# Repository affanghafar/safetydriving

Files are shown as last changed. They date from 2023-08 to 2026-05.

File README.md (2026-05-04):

# Driver Drowsiness Detection System using Heart Rate and Postural Changes

## Overview
This project develops a driver drowsiness detection system using physiological and motion data. The system combines heart rate signals and postural changes to classify driver fatigue levels using a Fuzzy Inference System.

---

## System Overview

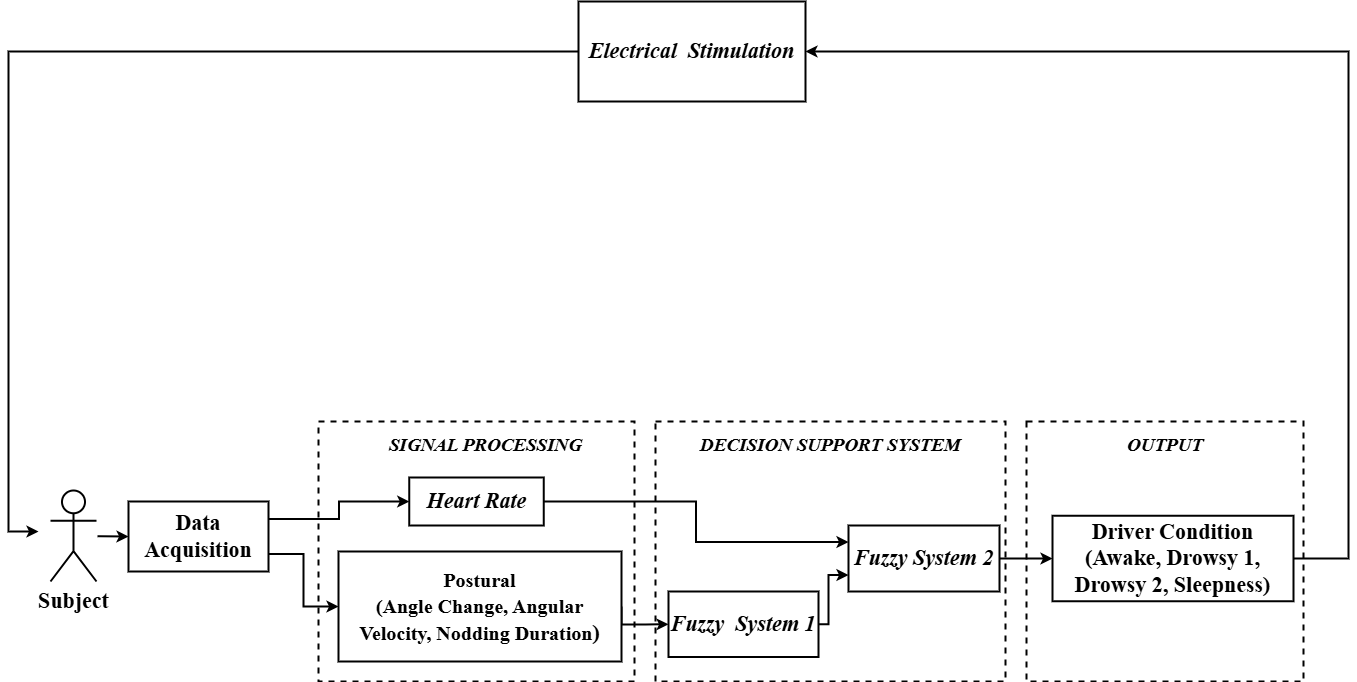
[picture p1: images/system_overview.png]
System Diagram


*Overall functional system diagram for driver drowsiness detection.*

---

## Hardware & Instrumentation

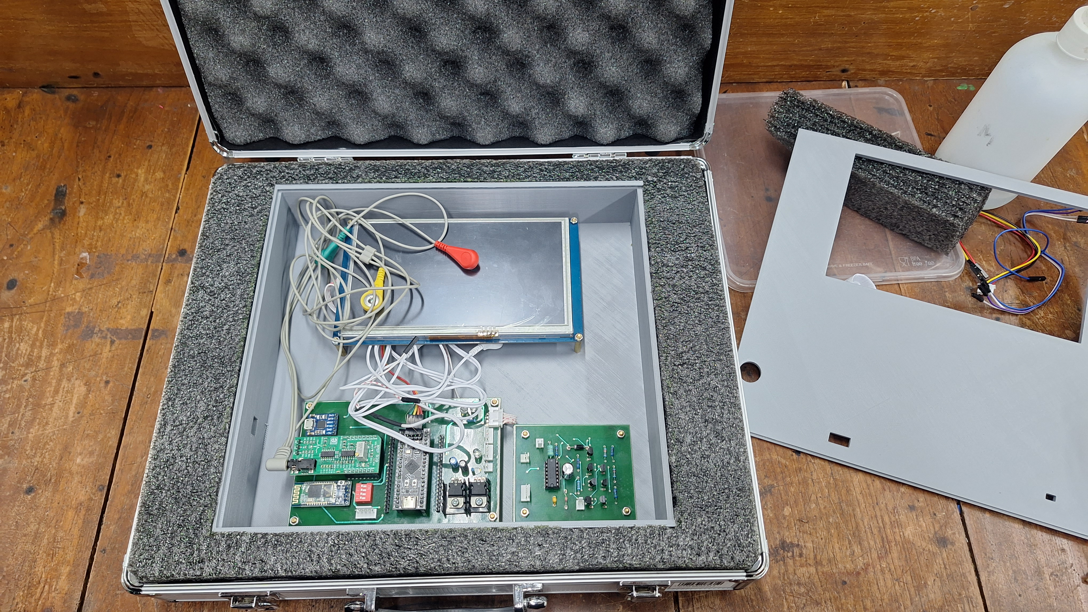
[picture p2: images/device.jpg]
Device


*Prototype device for acquiring ECG and postural data.*

---

## User Interface

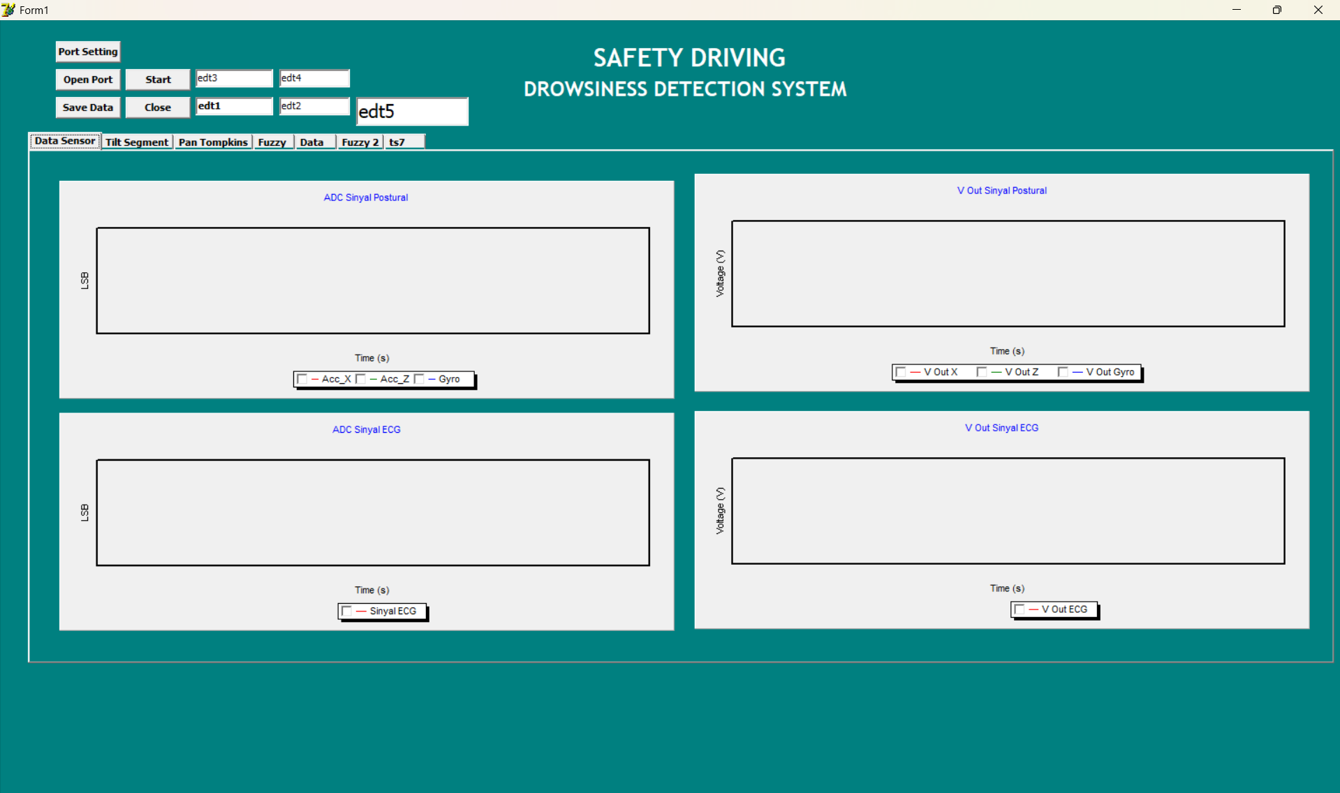
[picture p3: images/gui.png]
GUI


*Graphical user interface for monitoring and visualization.*

---

## Data Acquisition

### ECG Signal Acquisition
ECG Diagram

*Acquisition of heart rate signals using ECG sensor.*

---

### Postural Data Acquisition
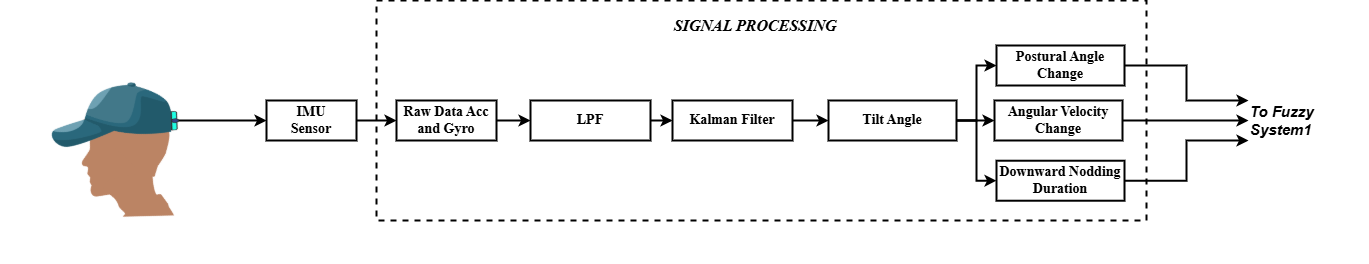
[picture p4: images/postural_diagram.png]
Postural Diagram


*Measurement of head movement and postural changes.*

---

## Hardware Design

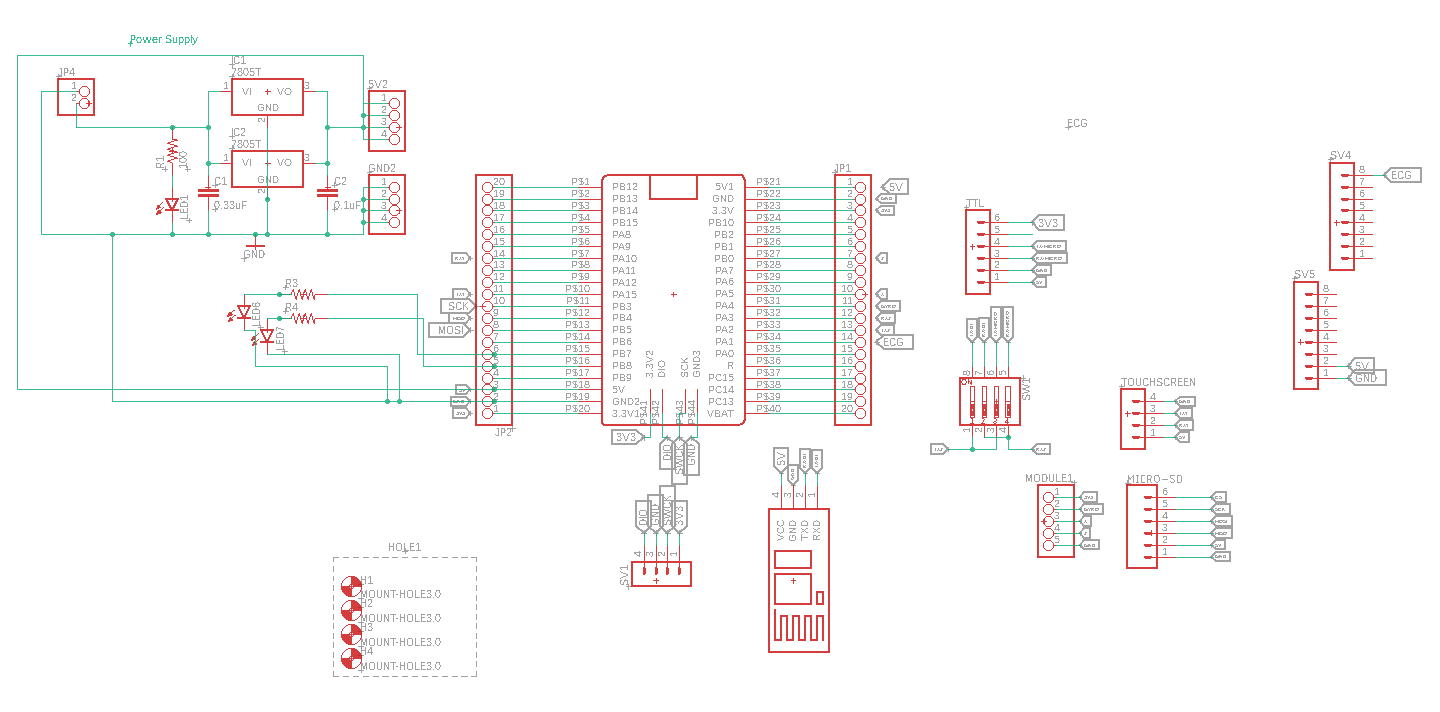
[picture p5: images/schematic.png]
Schematic


*Circuit schematic of the embedded system including ECG sensor and motion sensors.*

## Features

### Physiological Features
- Heart Rate (BPM)

### Postural Features
- Head angle
- Angular velocity
- Nodding duration

---

## Methodology

- Signal acquisition from ECG and motion sensors
- Feature extraction from physiological and postural data
- Classification using **Fuzzy Inference System (FIS)**

---

## Key Findings

- Heart rate tends to decrease during drowsiness
- Postural angle and nodding duration increase
- Angular velocity decreases as fatigue increases

---

## Performance

- Achieved overall accuracy of **87.14%**

---

## Technologies
- Embedded System (STM32)
- Signal Processing
- ECG Sensor
- Accelerometer & Gyroscope
- Fuzzy Logic (FIS)

---

## Project Structure
- `embedded/` – Embedded system code  
- `interface/` – GUI application  
- `hardware/` – PCB and device design  
- `images/` – Diagrams and visualization assets  

---

## Author
Afan Ghafar

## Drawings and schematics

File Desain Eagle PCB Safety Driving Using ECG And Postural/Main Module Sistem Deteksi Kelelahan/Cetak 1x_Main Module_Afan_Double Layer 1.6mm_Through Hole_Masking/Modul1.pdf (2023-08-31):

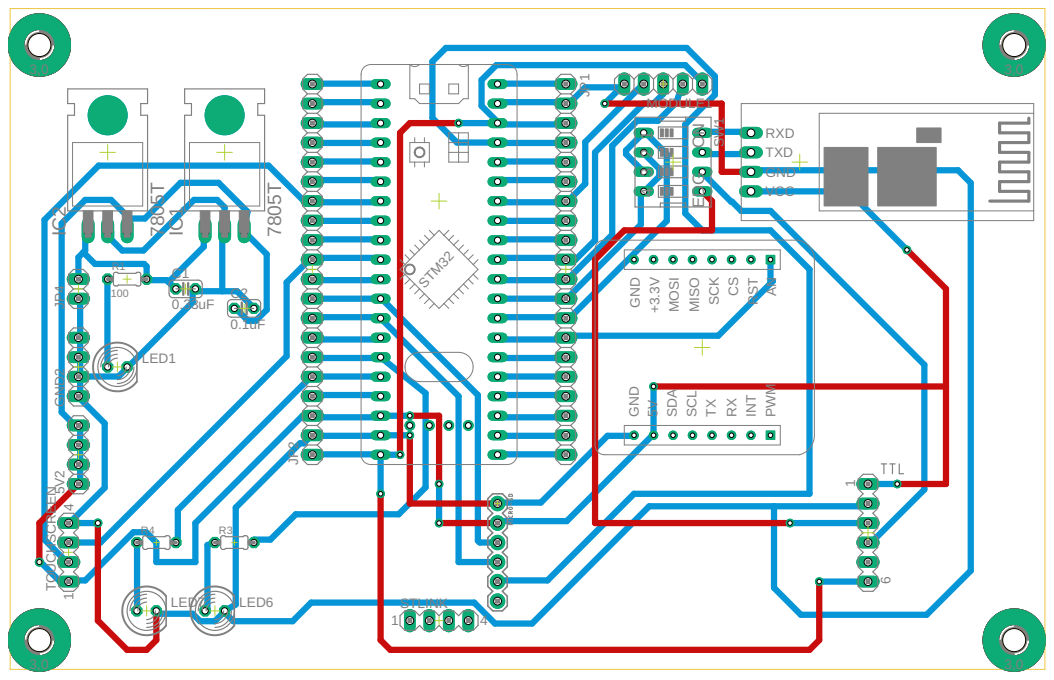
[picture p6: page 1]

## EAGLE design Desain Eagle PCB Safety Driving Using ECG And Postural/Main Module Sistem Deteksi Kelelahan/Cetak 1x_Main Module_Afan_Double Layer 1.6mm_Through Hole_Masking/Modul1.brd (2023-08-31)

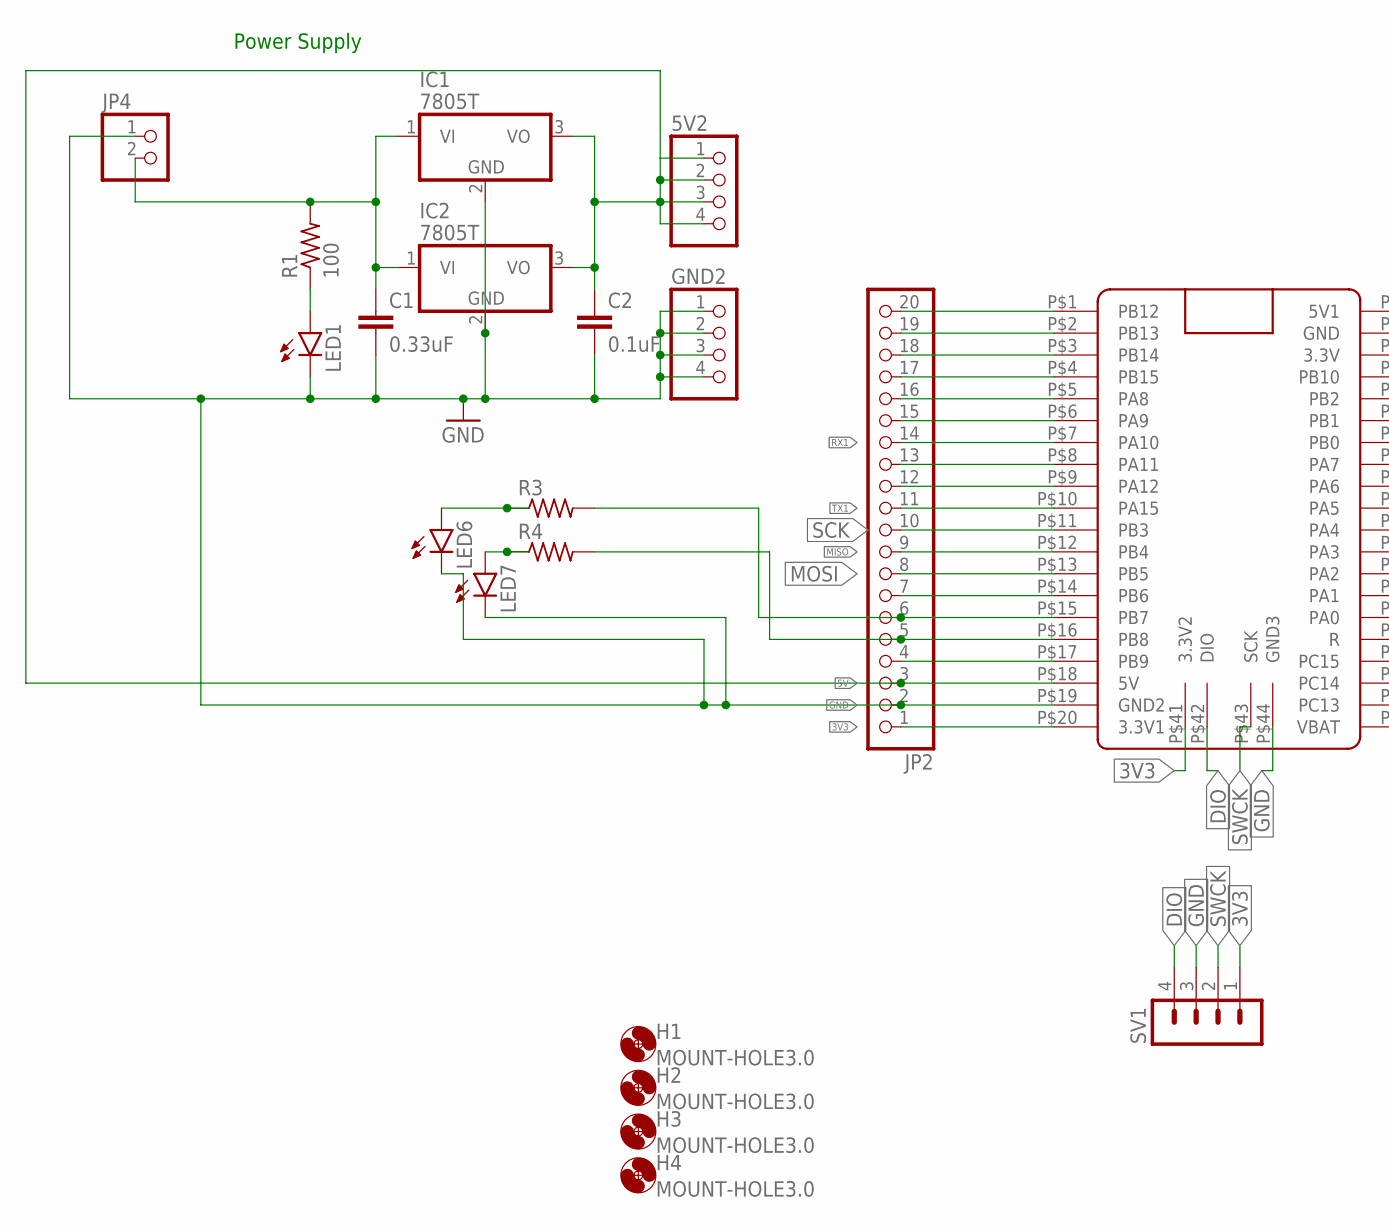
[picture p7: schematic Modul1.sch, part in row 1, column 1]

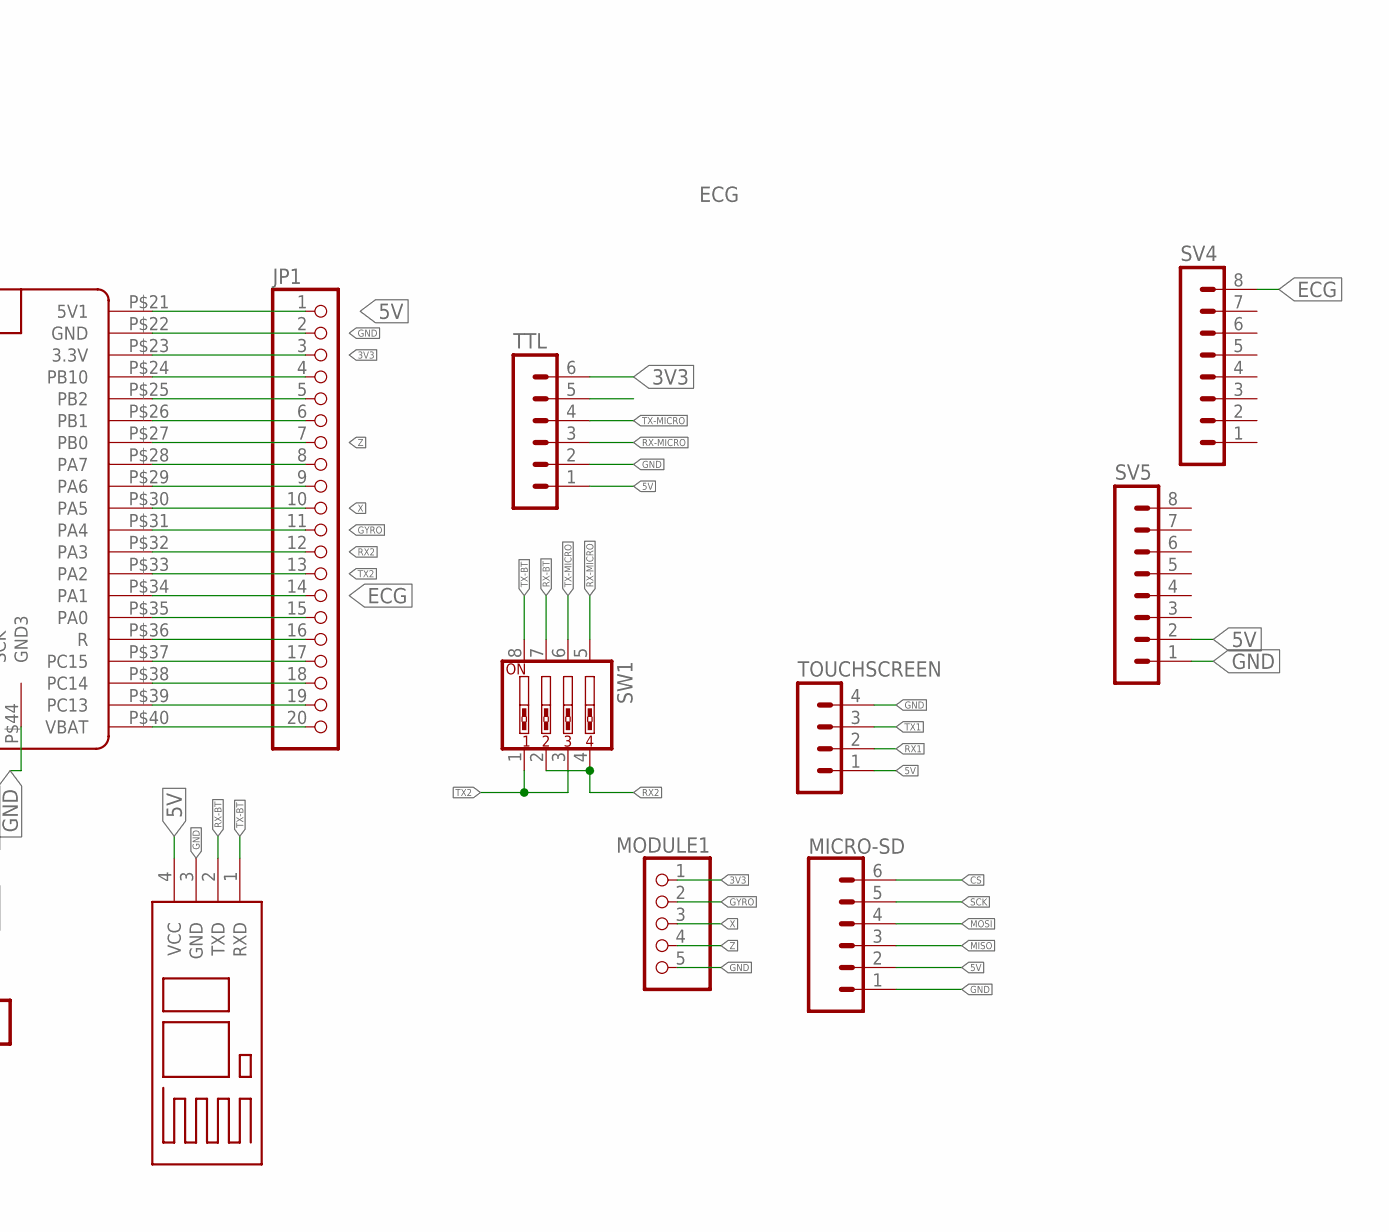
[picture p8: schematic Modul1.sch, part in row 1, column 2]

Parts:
5V2: PINHD-1X4; 1X04
B3: BLUETOOTH
C1: 0.33uF; C025-024X044
C2: 0.1uF; C025-024X044
GND2: PINHD-1X4; 1X04
H1, H2, H3, H4: MOUNT-HOLE3.0; 3,0
IC1, IC2: 7805T; TO220H
JP1, JP2: PINHD-1X20; 1X20
JP4: PINHD-1X2; 1X02
LED1, LED6, LED7: LED5MM
MICRO-SD: CONN_06SILK_FEMALE_PTH; 1X06@1
MODULE1: PINHD-1X5; 1X05
R1: 100; 0204/5
R3, R4: R-US_0204/5; 0204/5
SV1: MA04-1
SV4, SV5: MA08-1
SW1: SW_DIP-4; EDG-04
TOUCHSCREEN: MA04-1
TTL: MA06-1
U$1: BLACKPILL

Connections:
3V3: JP1.3, JP2.1, MODULE1.1, SV1.1, TTL.6, U$1.P$20 (3.3V1), U$1.P$23 (3.3V), U$1.P$41 (3.3V2)
5V: 5V2.1, 5V2.2, 5V2.3, 5V2.4, B3.4 (VCC), C2.1, IC1.3 (VO), IC2.3 (VO), JP1.1, JP2.3, MICRO-SD.2, SV5.2, TOUCHSCREEN.1, TTL.1, U$1.P$18 (5V), U$1.P$21 (5V1)
CS: MICRO-SD.6
DIO: SV1.4, U$1.P$42 (DIO)
ECG: JP1.14, SV4.8, U$1.P$34 (PA1)
GND: B3.3 (GND), C1.2, C2.2, GND2.1, GND2.2, GND2.3, GND2.4, IC1.2 (GND), IC2.2 (GND), JP1.2, JP2.2, JP4.1, LED1.K (C), LED6.K (C), LED7.K (C), MICRO-SD.1, MODULE1.5, SV1.3, SV5.1, TOUCHSCREEN.4, TTL.2, U$1.P$19 (GND2), U$1.P$22 (GND), U$1.P$44 (GND3)
GYRO: JP1.11, MODULE1.2, U$1.P$31 (PA4)
MISO: JP2.9, MICRO-SD.3, U$1.P$12 (PB4)
MOSI: JP2.8, MICRO-SD.4, U$1.P$13 (PB5)
unnamed: JP2.20, U$1.P$1 (PB12)
unnamed: JP2.19, U$1.P$2 (PB13)
unnamed: JP2.18, U$1.P$3 (PB14)
unnamed: C1.1, IC1.1 (VI), IC2.1 (VI), JP4.2, R1.2
unnamed: JP1.8, U$1.P$28 (PA7)
unnamed: JP1.4, U$1.P$24 (PB10)
unnamed: LED1.A, R1.1
unnamed: JP2.12, U$1.P$9 (PA12)
unnamed: JP2.5, R4.2, U$1.P$16 (PB8)
unnamed: LED6.A, R3.1
unnamed: LED7.A, R4.1
unnamed: JP2.7, U$1.P$14 (PB6)
unnamed: JP1.20, U$1.P$40 (VBAT)
unnamed: JP1.19, U$1.P$39 (PC13)
unnamed: JP1.18, U$1.P$38 (PC14)
unnamed: JP1.17, U$1.P$37 (PC15)
unnamed: JP1.16, U$1.P$36 (R)
unnamed: JP1.5, U$1.P$25 (PB2)
unnamed: JP1.6, U$1.P$26 (PB1)
unnamed: JP1.15, U$1.P$35 (PA0)
RX1: JP2.14, TOUCHSCREEN.2, U$1.P$7 (PA10)
RX2: JP1.12, SW1.2, SW1.4, U$1.P$32 (PA3)
RX-BT: B3.2 (TXD), SW1.7
RX-MICRO: SW1.5, TTL.3
SCK: JP2.10, MICRO-SD.5, U$1.P$11 (PB3)
SDA: JP2.4, U$1.P$17 (PB9)
SDIO_CK: JP2.17, U$1.P$4 (PB15)
SDIO_CMD: JP1.9, U$1.P$29 (PA6)
SDIO_D0: JP2.6, R3.2, U$1.P$15 (PB7)
SDIO_D1: JP2.16, U$1.P$5 (PA8)
SDIO_D2: JP2.15, U$1.P$6 (PA9)
SWCK: SV1.2, U$1.P$43 (SCK)
TX1: JP2.11, TOUCHSCREEN.3, U$1.P$10 (PA15)
TX2: JP1.13, SW1.1, SW1.3, U$1.P$33 (PA2)
TX6: JP2.13, U$1.P$8 (PA11)
TX-BT: B3.1 (RXD), SW1.8
TX-MICRO: SW1.6, TTL.4
X: JP1.10, MODULE1.3, U$1.P$30 (PA5)
Z: JP1.7, MODULE1.4, U$1.P$27 (PB0)

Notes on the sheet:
ECG
Power Supply

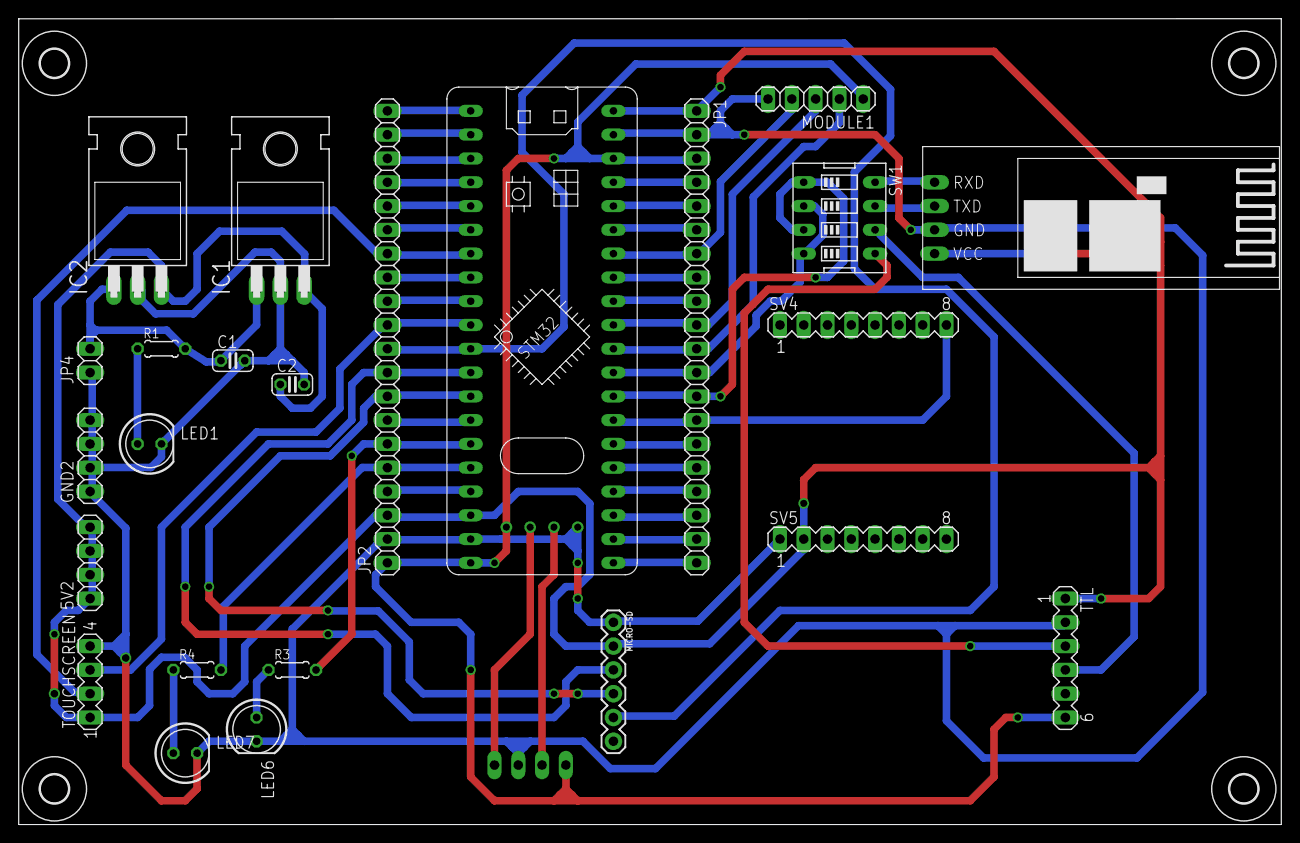
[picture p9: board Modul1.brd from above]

Board: 2 copper layers, 134.8 x 86.0 mm, 29 parts (1 on the bottom side), 47 nets.

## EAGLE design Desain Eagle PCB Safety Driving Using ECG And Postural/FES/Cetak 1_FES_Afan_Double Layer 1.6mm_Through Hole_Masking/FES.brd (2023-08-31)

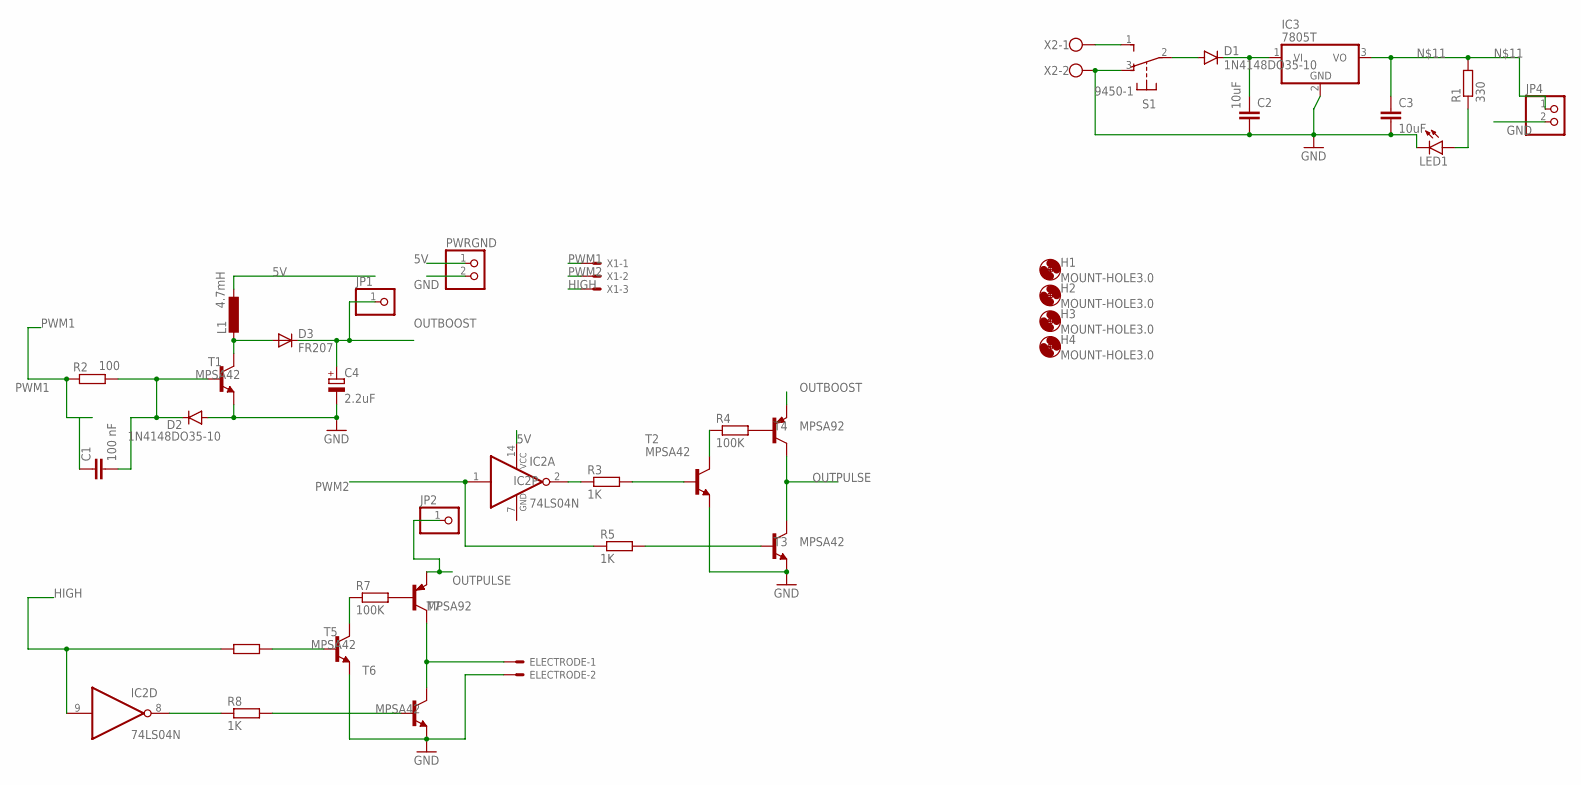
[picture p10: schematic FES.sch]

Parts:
C1: 100 nF; C5B2.5
C2, C3: 10uF; C2.5-2
C4: 2.2uF; E5-10,5
D1, D2: 1N4148DO35-10; DO35-10
D3: FR207; DO15-12
ELECTRODE: 22-23-2021
H1, H2, H3, H4: MOUNT-HOLE3.0; 3,0
IC2: 74LS04N; DIL14
IC3: 7805T; TO220H
JP1, JP2: PINHD-1X1; 1X01
JP4: PINHD-1X2; 1X02
L1: 4.7mH; 0207/12
LED1: LED3MM
PWRGND: PINHD-1X2; 1X02
R1: 330; 0207/10
R2: 100; 0207/10
R3, R5, R6, R8: 1K; 0207/10
R4, R7: 100K; 0207/10
S1: 9450-1
T1, T2, T3, T5, T6: MPSA42; TO92-EBC
T4, T7: MPSA92; TO92-EBC
X1: 22-23-2031
X2: W237-102

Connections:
5V: IC2.14 (VCC), L1.1, PWRGND.1
GND: C2.2, C3.2, C4.-, D2.A, ELECTRODE.2, IC2.7 (GND), IC3.2 (GND), JP4.2, LED1.K (C), PWRGND.2, S1.3 (O), T1.E, T2.E, T3.E, T5.E, T6.E, X2.2
HIGH: IC2.9 (I), R6.1, X1.3
unnamed: C1.2, D2.C, R2.2, T1.B
unnamed: S1.1 (S), X2.1
unnamed: D3.A, L1.2, T1.C
unnamed: C2.1, D1.C, IC3.1 (VI)
unnamed: R4.2, T4.B
unnamed: IC2.2 (O), R3.1
unnamed: R3.2, T2.B
unnamed: R4.1, T2.C
unnamed: R7.2, T7.B
unnamed: C3.1, IC3.3 (VO), JP4.1, R1.2
unnamed: IC2.8 (O), R8.1
unnamed: R5.2, T3.B
unnamed: R6.2, T5.B
unnamed: R7.1, T5.C
unnamed: ELECTRODE.1, T6.C, T7.C
unnamed: R8.2, T6.B
unnamed: LED1.A, R1.1
unnamed: D1.A, S1.2
OUTBOOST: C4.+, D3.C, JP1.1, T4.E
OUTPULSE: JP2.1, T3.C, T4.C, T7.E
PWM1: C1.1, R2.1, X1.1
PWM2: IC2.1 (I), R5.1, X1.2

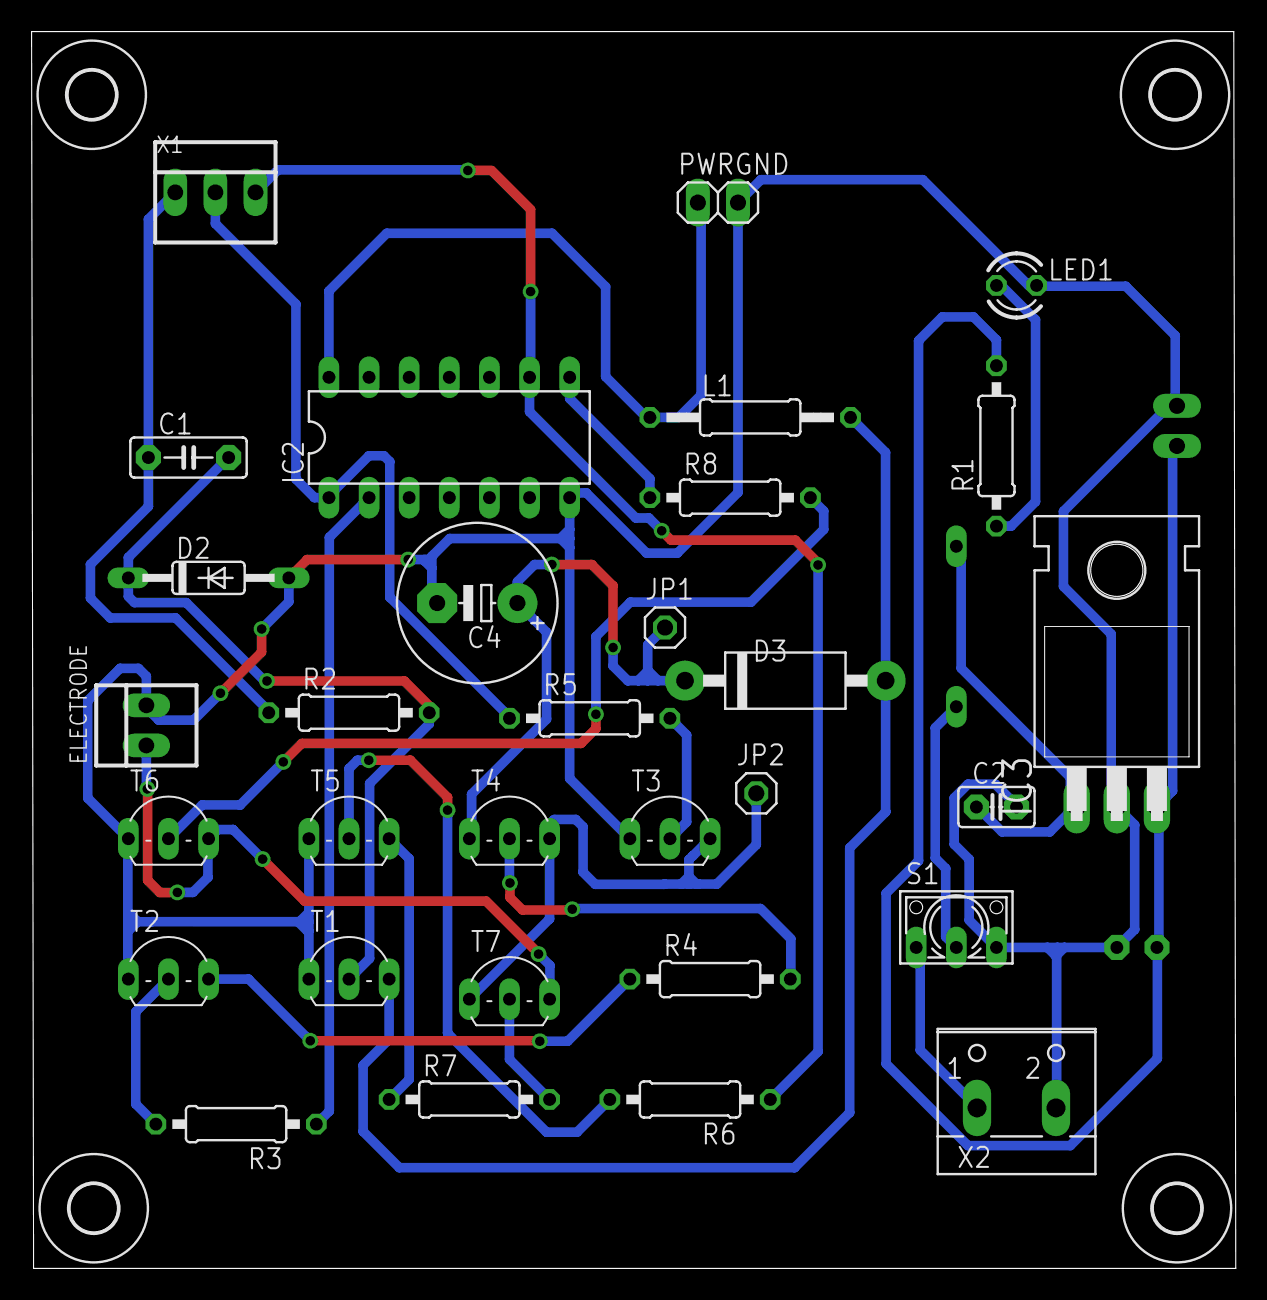
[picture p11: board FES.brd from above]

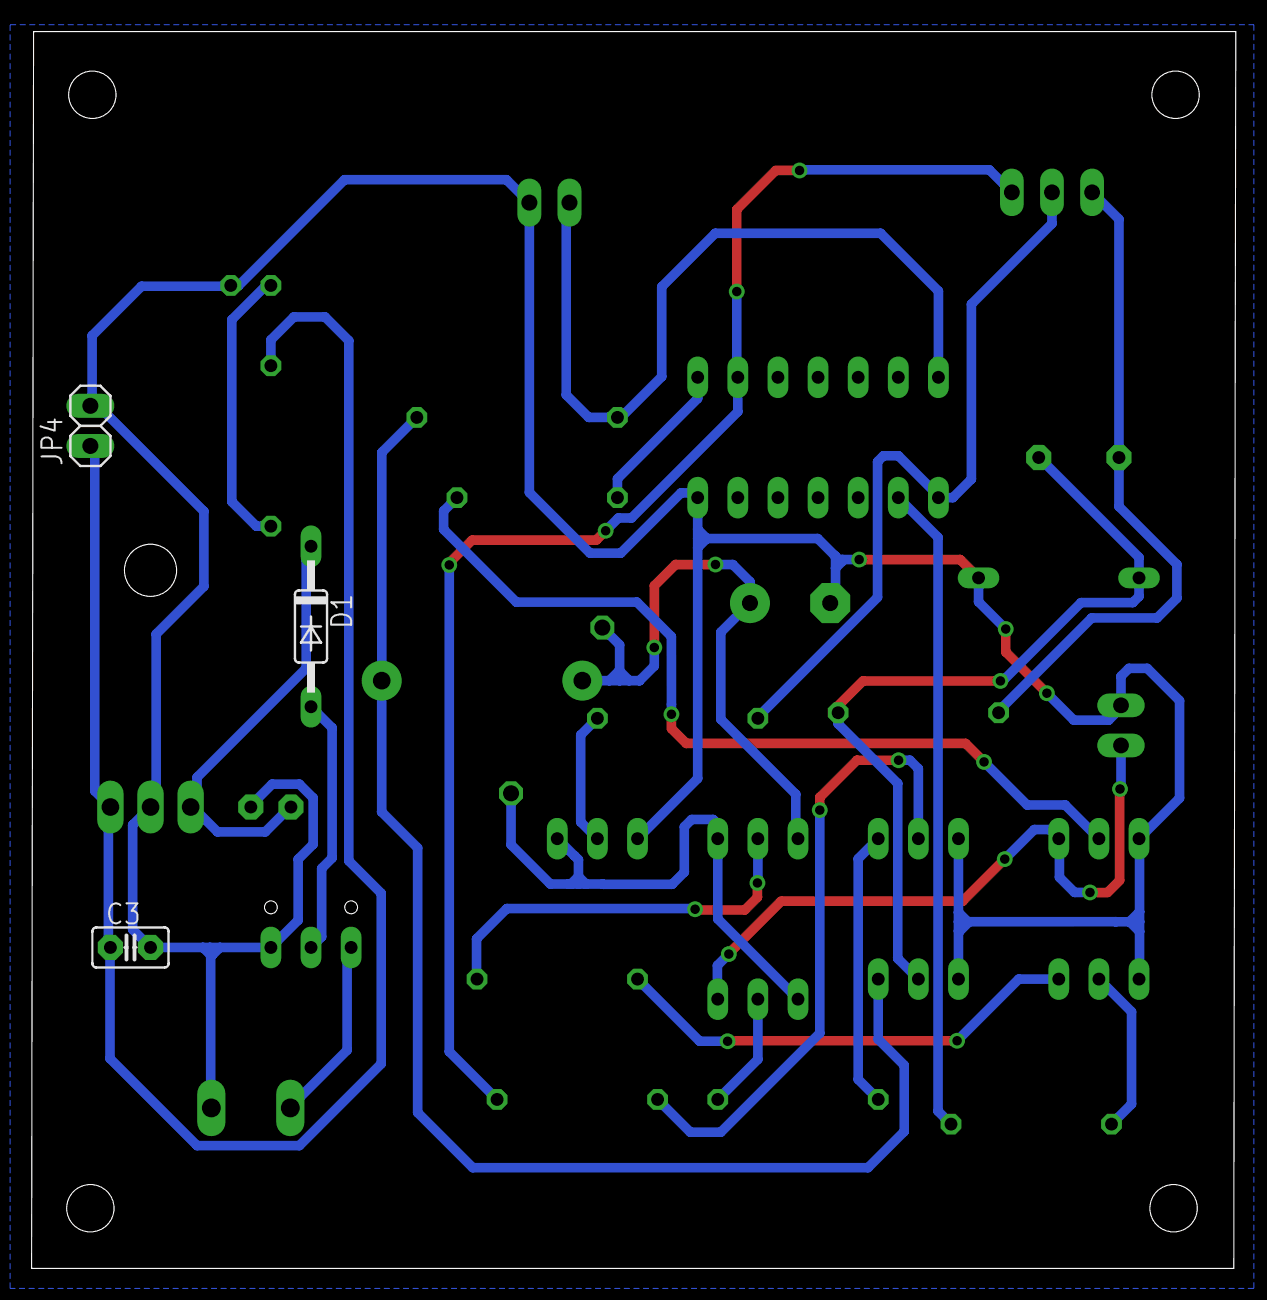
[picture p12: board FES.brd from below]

Board: 2 copper layers, 76.2 x 78.3 mm, 38 parts (3 on the bottom side), 25 nets.

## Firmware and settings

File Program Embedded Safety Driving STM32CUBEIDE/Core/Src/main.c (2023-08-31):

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
/* Includes ------------------------------------------------------------------*/
#include "main.h"
#include "usb_device.h"
#include <math.h>
#include "usbd_cdc_if.h"
#include <malloc.h>
#include "string.h"
#include <stdio.h>
#include <stdlib.h>

ADC_HandleTypeDef hadc1;

SPI_HandleTypeDef hspi1;

TIM_HandleTypeDef htim1;
TIM_HandleTypeDef htim2;
TIM_HandleTypeDef htim4;

UART_HandleTypeDef huart1;
UART_HandleTypeDef huart2;

/* USER CODE BEGIN PV */


uint8_t fsampling=250;
#define filter_length 750 //fs*waktu
#define th 37
int kondisi_sebelum, kondisi_sekarang;
float lpf[filter_length],hpf[filter_length],derivativ[filter_length],squaring[filter_length],moving[filter_length],moving1[filter_length],threshold[filter_length],threshold1[filter_length],threshold2[filter_length],qrs[filter_length],threshold3[filter_length],threshold4[filter_length];
uint16_t Acc1x=0,ecg,gyro1=0, Acc1z=0,Acc1xa,Acc1xb,Acc1za,Acc1zb, gyro1a,gyro1b;
uint8_t rx_data1,rx_data;
uint8_t  myData[24];
uint32_t on=0, off=0, timerCount=0, fes=0, fes2=0, tmr=0;
uint32_t count3=0,count4=0,n=0,count5=0,count2=0,count1=0,windowing=0,p=0,count_rr=0,k=0,z1=0,q1=0,count6=0, count7=0;
uint8_t Cmd_End[3] = {0xFF,0xFF,0xFF};
float d,e,f,g,h,l,hr,ecg_vol[filter_length],durasi,o,t,v;
float a11, b11, c11, d11,e11,f11,g11,h11,l11;
float a22, b22, c22, d22,e22,f22,g22,h22,l22;
int m;
float max_value,ecg_lpf,ecg_hpf,deriv,squar,mav, mav1,thr,bpm1;


//------------------------Const Sinyal ECG----------------------------//


//------------------------Const Untuk Postural----------------------------//
//#define FrekSampling	20			// dalam Hz
//#define dt 				0.05	// dalam detik
#define FrekSampling	250			// dalam Hz
#define dt 				0.004		// dalam detik
#define pi 				3.141593
#define d90 			90
#define Rad2Deg 		57.29578
//0g acc (kalibrasi)
#define UparmAc_X_0g	  (2457+1642)/2//(2537+1393)/2 //(2412+1592)/2//1861.36
#define UparmAc_Z_0g	  (2431+1633)/2//(2472+1345)/2 //(2432+1627)/2
//--------sensitivitas acc (kalibrasi)
#define UparmAc_X_Sens	 (2457-1642)/2//(2537-1393)/2 //(2412-1592)/2
#define UparmAc_Z_Sens	 (2431-1633)/2//(2472-1345)/2 //(2432-1627)/2
//Koefisien Regresi kalibrasi
#define aUparm 	0.9971
#define bUparm 	0.0585
//--------sensitivitas gyro (sesuai data sheet)(4095*0.00067/3.3)
#define GyroSenstvtS 	1.16 //2.7
//--------gyro offset (kalibrasi lsb kondisi diam)
#define Gyro_offset	1671



//ADC_ChannelConfTypeDef sConfig = {0};
/* USER CODE END PV */

void SystemClock_Config(void);
static void MX_GPIO_Init(void);
static void MX_ADC1_Init(void);
static void MX_TIM2_Init(void);
static void MX_USART1_UART_Init(void);
static void MX_USART2_UART_Init(void);
static void MX_SPI1_Init(void);
static void MX_TIM1_Init(void);
static void MX_TIM4_Init(void);

ADC_ChannelConfTypeDef sConfig = {0};
/* USER CODE END PV */
//================== DIGITAL Butterworth LPF ======================//
static const float a1 =  1.6474599811; static const float a2 = 0.7008967812; //4Hz
static const float b0 =  0.0133592000; static const float b1 = 0.0267184001;
static const float b2 =  0.0133592000;
//================== KALMAN FILTER Uparm
static const float QangleS = 0.001;  //tingkat kepercayaan Akselero Uparm
static const float QgyroS  = 0.003;  //tingkat kepercayaan Gyro Uparm
static const float RangleS = 0.04;	 //kemungkinan jiter Akselero Uparm (rad)

float UparmLajuGr, TiltUparmGr, UparmAc_X_Vctr,UparmAc_Z_Vctr,UparmAcclX_LPF, UparmAcclZ_LPF,UparmGyroY_LPF, t=0,miuk ;
float TiltAc=0.0,Tilttemp, TiltKal,GyroUparm, VUparmx,VUparmz,VgyroUparm,sudut[filter_length],velocity[filter_length],signal1[filter_length];
int cntr, Uparmac_a,Uparmac_b,Uparmkal_a,Uparmkal_b,ri;
int gyroUparma,gyroUparmb,gyroUparmc;
int VUparmx_a,VUparmx_b,VUparmz_a,VUparmz_b, VgyroUparm_a,VgyroUparm_b,Vecg_a,Vecg_b;
float ErrEstmt, K0, K1, ErrTilt,error1,tarr,heart_rate;
float Bias_T, P1T, P2T, P3T, P4T,Bias_S, P1S, P2S, P3S, P4S,Bias_F, P1F, P2F, P3F, P4F;
int sinyal[14],sinyal_1[14],sinyal_2[14],Ylpf[14],Ylpf_1[14],Ylpf_2[14];
int sinyal_1_acc1x[14],sinyal_2_acc1x[14],Ylpf_1_acc1x[14],Ylpf_2_acc1x[14];
int sinyal_1_acc1z[14],sinyal_2_acc1z[14],Ylpf_1_acc1z[14],Ylpf_2_acc1z[14];
int sinyal_1_gyro1y[14],sinyal_2_gyro1y[14],Ylpf_1_gyro1y[14],Ylpf_2_gyro1y[14];
int gyroUparma,gyroUparmb,gyroUparmc;

int flag,Program_state, flagkirim, map_ecg,i,Elpf_a,Elpf_b,Ehpf_a,Ehpf_b,panjang_bpm[filter_length];
int deriv_a,deriv_b,squar_a,squar_b, mav_a,mav_b,window,mav_a1,mav_b1,thr_a,thr_b,rr_a,rr_b,rr1_a,rr1_b,bpm_a,bpm_b;
char ecg_kirim[5], ecg_data[20], hasil_data[5],map_hasil;
char Rx_data[1];
float Vecg,Vecg1,count,tho,AN,AP,rr_temp[filter_length],rr1[0][filter_length],nilairr[filter_length];
int count_k[filter_length];
int qrs_hasil;
float ecg_vol1[filter_length], off_ecg_temp,sum,sum_data, kecepatan;
float hasil1[filter_length], hasil2[filter_length], hasil3[filter_length];
float hasil_QRS[filter_length];
float ZrTiltUparmAc, zeroposition;
float signal[filter_length];
float rr_index[filter_length],rr[filter_length],bpm[filter_length];
uint32_t rr_index_length=0,rr_length=0;
//fuzzy
int lop,j,m,q,stmltime,stmltime_1,stmltime2,stmltime_2,stmltime3,stmltime_3,cntrTA;
float a,b,c,jfloat, jfloat1, jfloat2, jfloat3, jfloat4, in1,in2,in3,in4,in5[filter_length],in6[filter_length], in7[filter_length], in8[filter_length], min[24],imfhr[3][3],imfkc[3][3],imfdr[4][4],imfps[3][3],omfstbd[4][4],miu[8],miuerr[8],miudr[8],miumaxstbd[101],maxplantar,maxflexion,maxflexion1;
float maxx,fuzzy_mks[10],ttk[10],num,denum,centroid,AnkKal_Save,AnkKal_Save2,ShoulderKal_Save;
int in1a,in1b,in2a,in2b,in3a,in3b,in4a,in4b,in5a,in5b,centa,centb,centc,centd,cente,centf,gyroShouldera,gyroShoulderb,gyroShoulderc,gyroUparma,gyroUparmb,gyroUparmc,gyroLowarma,gyroLowarmb,gyroLowarmc;
float miu_low[filter_length], miu_vhigh1[filter_length],miu_high[filter_length],miu_low1[filter_length], miu_medium1[filter_length],miu_high1[filter_length],miu_low2[filter_length],miu_high2[filter_length],miu_low3[filter_length],miu_medium3[filter_length],miu_high3[filter_length];
float miuk_low, miuk_medium, miuk_high, miuk_low1, miuk_medium1, miuk_high1,miuk_vhigh1;
float miul_hr, mium_hr, miuh_hr, miul_pos, miuh_pos, miul_kec, miuh_kec,mius_dur,mium_dur,miul_dur,miuvl_dur;
float rule[27], sum_rr = 0.0;
float value_a, value_w1, value_w2, value_w3, outf;
float low_miu, medium_miu, high_miu,max1, max2,max3,max4;
float value_aw, value_dr1, value_dr2,value_sl, value_rmssd;
float miu_low3[filter_length], miu_medium3[filter_length], miu_high3[filter_length],miu_low4[filter_length], miu_medium4[filter_length], miu_high4[filter_length],miu_vhigh4[filter_length];
/* USER CODE BEGIN PFP */



void Kalman(void)
{
	sinyal[1]=Acc1x;
	sinyal[2]=Acc1z;
	sinyal[3]=gyro1;

	//LPF filter
	for (i = 1; i < 4; i++)
	{
		if (i==1){
			Ylpf_2[i] = Ylpf_2_acc1x[i];
			Ylpf_1[i] = Ylpf_1_acc1x[i];
			sinyal_2[i] = sinyal_2_acc1x[i];
			sinyal_1[i] = sinyal_1_acc1x[i];
		}
		else if (i==2){
			Ylpf_2[i] = Ylpf_2_acc1z[i];
			Ylpf_1[i] = Ylpf_1_acc1z[i];
			sinyal_2[i] = sinyal_2_acc1z[i];
			sinyal_1[i] = sinyal_1_acc1z[i];
		}
		else if (i==3){
			Ylpf_2[i] = Ylpf_2_gyro1y[i];
			Ylpf_1[i] = Ylpf_1_gyro1y[i];
			sinyal_2[i] = sinyal_2_gyro1y[i];
			sinyal_1[i] = sinyal_1_gyro1y[i];
		}

		Ylpf[i] = (uint16_t)(a1*((float)Ylpf_1[i])-a2*((float)Ylpf_2[i])+b0*((float)sinyal[i])+b1*((float)sinyal_1[i])+b2*((float)sinyal_2[i]));
		if (Ylpf[i]<0){Ylpf[i]=0;}

		if (i==1){
			Ylpf_2_acc1x[i] = Ylpf_1[i];
			Ylpf_1_acc1x[i] = Ylpf[i];
			sinyal_2_acc1x[i] = sinyal_1[i];
			sinyal_1_acc1x[i] = sinyal[i];
		}
		else if (i==2){
			Ylpf_2_acc1z[i] = Ylpf_1[i];
			Ylpf_1_acc1z[i] = Ylpf[i];
			sinyal_2_acc1z[i] = sinyal_1[i];
			sinyal_1_acc1z[i] = sinyal[i];
		}
		else if (i==3){
			Ylpf_2_gyro1y[i] = Ylpf_1[i];
			Ylpf_1_gyro1y[i] = Ylpf[i];
			sinyal_2_gyro1y[i] = sinyal_1[i];
			sinyal_1_gyro1y[i] = sinyal[i];
		}
	}

	//using lpf
	UparmAcclX_LPF = Ylpf[1];
	UparmAcclZ_LPF = Ylpf[2];
	UparmGyroY_LPF = Ylpf[3];

	UparmAc_X_Vctr = (float)((UparmAcclX_LPF - UparmAc_X_0g)/ UparmAc_X_Sens);
	UparmAc_Z_Vctr = (float)((UparmAcclZ_LPF - UparmAc_Z_0g)/ UparmAc_Z_Sens);


	TiltAc	=  atan2f(UparmAc_Z_Vctr,UparmAc_X_Vctr);


	TiltAc	= TiltAc*Rad2Deg;

//	if (zeroposition==1.0)
//	    	{
//	    		ZrTiltUparmAc	= TiltAc;
////	    		ZeroHip = ZrTiltThighAc - ZrTiltTrunkAc;
//	    		TiltKal = TiltAc;
//	    	}

//---------------------------------KALMAN FILTER------------------------------------//

    //--------------------- Time Update / State Update: ( “Prediksi ? )
    //------ prediksi state
    UparmLajuGr = (float)((UparmGyroY_LPF-Gyro_offset)/GyroSenstvtS);
    TiltKal += (UparmLajuGr - Bias_S)*dt; //TiltUparm = nilai Prediksi

//    GyroUparm += (UparmLajuGr * dt); //TiltShoulder = nilai Prediksi

//    TiltKal = TiltAc - TiltKal;
    // += (UparmLajuGr * dt); //TiltShoulder = nilai Prediksi
    //GyroUparm *= Rad2Deg;

    //------ prediksi matrik Error Covariance
    //??
    P4S += QgyroS * dt;
    P2S -= P4S * dt;
    P3S -= P4S * dt;
    P1S += (QangleS + P4S*dt - P3S - P2S )*dt;

    //--------------------- Measurement Update / Kalman Update (  “Koreksi ? )
    //------ hitung Error Estimate
    //??
    ErrEstmt = P1S + RangleS;

    //------ hitung Kalman filter Gain
    K0 = P1S / ErrEstmt;
    K1 = P3S / ErrEstmt;
    //pembaharuan
    //------ hitung tilt error, selisih nilai measurement - nilai Prediksi state
    ErrTilt  = TiltAc - TiltKal;  //TiltAc = nilai Measurement

    //------ Koreksi nilai estimasi state
    TiltKal += K0 * ErrTilt;  //estimasi sudut tilt Uparm terkoreksi
    Bias_S    += K1 * ErrTilt;  //estimasi bias gyro terkoreksi, perb output dan real

    //------ Koreksi matrik Error Covariance ->utk iterasi berikutnya
    P1S -= K0 * P1S;
    P2S -= K0 * P2S;
    P3S -= K1 * P1S;
    P4S -= K1 * P2S;

//    TiltKal = TiltAc - TiltKal;
}

void vel(void){



 if(count3==0){
	 sudut[count2]=TiltKal;

	 if(count2==0) velocity[count2]=0.0;
	 else velocity[count2]=(sudut[count2]-sudut[count2-1])/dt;
 }
 else{
	 sudut[count2]=TiltKal;
	 if(count2==0)velocity[count2]=(sudut[count2]-sudut[filter_length+count2-1])/dt;
	 else velocity[count2]= (sudut[count2]-sudut[count2-1])/dt;
 }


 kecepatan=fabs(velocity[count2]);
 count2++;

 if(count2==filter_length){
	 count3=1;
	 count2=0;
 }
}

void time(void){

 if(TiltKal>43.0){
 count6 +=1;
	}
else{
count6 =0;
}
durasi = count6/250.0;
}

//void time(void){
//
// if(TiltKal<=41.0){
//	 kondisi_sekarang=0;
//	 }
// else{
//	 kondisi_sekarang=1;
// }
// if(kondisi_sekarang!=kondisi_sebelum){
//   count6 = 0;
//   kondisi_sebelum=kondisi_sekarang;
// }
// else{
//	 count6 += 1;
// }
//durasi = count6/250.0;
//}

float get_index(float *array, int n) {
    if(n < 0) {
        return array[0];
    }
    return array[n];
}

float get_rotating_index(float *array, int max, int n) {
    if(n < 0) {
        return array[max + (n)];
    }
    return array[n];
}

void PanTompkins(void)
{
	count1 = k % filter_length;
	//count_rr = q % filter_length;
//	if(count2==0){
		ecg_vol[count1]=(float)ecg*3.3/4095;

//
                      sum_data = sum_data + ecg_vol[count1];
                      ecg_vol[count1] = ecg_vol[count1] - (sum_data/(z1 + 1));

                      //Max Value
//                      if(count1==0){
//      	                 max_value=ecg_vol[count1];
//                      }
//                      if(ecg_vol[count1]>max_value){
//      	                 max_value=ecg_vol[count1];
//                      }


                    //  w2fb1[count1] = qj1[0] * signal[count1] +  qj1[1] * get_rotating_index(signal, filter_length,count1-1);
                      lpf[count1] = 2*get_rotating_index(lpf, filter_length,count1-1)-get_rotating_index(lpf, filter_length,count1-2)
                    		                  +ecg_vol[count1]-2*get_rotating_index(ecg_vol, filter_length,count1-6)+get_rotating_index(ecg_vol, filter_length,count1-12);
                      hpf[count1] = get_rotating_index(lpf, filter_length,count1-16)-get_rotating_index(lpf, filter_length,count1-1)/32.0-lpf[count1]/32.0
                    		                  +get_rotating_index(lpf, filter_length,count1-32)/32.0;
                      derivativ[count1] =(1.0/8.0)*get_rotating_index(hpf, filter_length,count1-1)+2*hpf[count1]-get_rotating_index(hpf, filter_length,count1-3)-2*get_rotating_index(hpf, filter_length,count1-4);
                      squaring[count1] = pow(derivativ[count1],2);
                      //Moving Average
					 window=50;
					 sum=0.0;
					 for (j = 0; j <= window; j++)
					 {
						 sum=sum+get_rotating_index(squaring, filter_length,count1-(window-j));
					 }
					 moving[count1] =((1.0/window)*sum);
//
//	                 //Thresholding
	                 if(moving[count1]>get_rotating_index(moving1, filter_length,count1-1)){
	                	 moving1[count1] = moving[count1];
	                 }
	                 else{
	                	 moving1[count1]=get_rotating_index(moving1, filter_length,count1-1);
	                	 if(moving[count1]<=get_rotating_index(moving1, filter_length,count1-1)/2.0){
	                	 moving1[count1] = moving[count1];
	                	 }
	                 }
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
int main(void)
{
	Bias_T = 0; Bias_S = 0; Bias_F = 0;
	P1T = 0; P2T = 0; P3T = 0; P4T = 0;
	P1S = 0; P2S = 0; P3S = 0; P4S = 0;
	P1F = 0; P2F = 0; P3F = 0; P4F = 0;

	ZrTiltUparmAc = 0.0;
	zeroposition=0.0;


	 //----------------------INPUT MEMBERSHIP HEART RATE-----------------------//
			imfhr[0][0] = 0.0;	imfhr[0][1] = 60.0;		imfhr[0][2] = 80.0;
			imfhr[1][0] = 63.4;	imfhr[1][1] = 80.0;		imfhr[1][2] = 95.6;
			imfhr[2][0] = 90.0;	imfhr[2][1] = 100.0;	imfhr[2][2] = 140.0;

			//------------------INPUT MEMBERSHIP FUNCTION DATA POSTURAL------------------//
			imfps[0][0] = 0.0;	imfps[0][1] = 43.0;		imfps[0][2] = 53.0;
			imfps[1][0] = 43.0;	imfps[1][1] = 53.0;		imfps[1][2] = 135.0;

			//------------------INPUT MEMBERSHIP FUNCTION DATA KECEPATAN SUDUT------------------//
			imfkc[0][0] = 0.0;	    imfkc[0][1] = 625.0;		imfkc[0][2] = 898.0;
			imfkc[1][0] = 625.0;	imfkc[1][1] = 898.0;		imfkc[1][2] = 3500.0;

			//------------------INPUT MEMBERSHIP FUNCTION DURASI------------------//
			imfdr[0][0] = 0.0;	imfdr[0][1] = 10;		imfdr[0][2] = 15;
			imfdr[1][0] = 10;	imfdr[1][1] = 18 ;		imfdr[1][2] = 26;
			imfdr[2][0] = 22;	imfdr[2][1] = 30;		imfdr[2][2] = 38;
			imfdr[3][0] = 33;	imfdr[3][1] = 40;		imfdr[3][2] = 70;

//			//----------------------OUTPUT MEMBERSHIP FUNCTION------------------------//
			omfstbd[0][0] = 0.0;  	omfstbd[0][1] = 30.0;	omfstbd[0][2] = 40.0;
			omfstbd[1][0] = 30.0;	omfstbd[1][1] = 45.0;	omfstbd[1][2] = 60.0;
			omfstbd[2][0] = 50.0;  	omfstbd[2][1] = 65.0;	omfstbd[2][2] = 80.0;
			omfstbd[3][0] = 70.0;  	omfstbd[3][1] = 80.0;	omfstbd[3][2] = 100.0;

  /* MCU Configuration--------------------------------------------------------*/

  /* Reset of all peripherals, Initializes the Flash interface and the Systick. */
  HAL_Init();

  /* Configure the system clock */
  SystemClock_Config();

  /* Initialize all configured peripherals */
  MX_GPIO_Init();
  MX_ADC1_Init();
  MX_TIM2_Init();
  MX_USB_DEVICE_Init();
  MX_USART1_UART_Init();
  MX_USART2_UART_Init();
  MX_SPI1_Init();
  MX_TIM1_Init();
  MX_TIM4_Init();
  TIM1->CCR1=6;
  HAL_TIM_PWM_Start(&htim1,TIM_CHANNEL_1);
  HAL_TIM_PWM_Start(&htim4,TIM_CHANNEL_2);
  HAL_GPIO_WritePin(GPIOB,GPIO_PIN_15,0);
  /* USER CODE BEGIN 2 */
  HAL_TIM_Base_Start_IT(&htim2);
  HAL_UART_Receive_IT (&huart1, Rx_data, sizeof(Rx_data));
  HAL_UART_Receive_IT(&huart2,Rx_data,1);
//  HAL_UART_Transmit_IT(&huart1, Cmd_End, 3);
//  HAL_UART_Transmit_IT(&huart1, ecg_data, strlen(ecg_data));
//


  /* USER CODE END 2 */

  /* Infinite loop */
  /* USER CODE BEGIN WHILE */
  while (1)
  {
	  if(Program_state==1){
	  			  if(flag==1){
	  //
	  			  			  flag=0;
	  		  			      ADC_Select_CH1();
	  		  			  	  HAL_ADC_Start(&hadc1);
	  		  			 	  HAL_ADC_PollForConversion(&hadc1, 1000);
	  		  			 	  ecg = HAL_ADC_GetValue(&hadc1);;
	  		  			 	  HAL_ADC_Stop(&hadc1);

	  		  			 	  ADC_Select_CH5();
	  		  			 	  HAL_ADC_Start(&hadc1);
	  		  			 	  HAL_ADC_PollForConversion(&hadc1, 1000);
	  		  			 	  Acc1x = HAL_ADC_GetValue(&hadc1);;
	  		  			 	  HAL_ADC_Stop(&hadc1);

	  		  			 	  ADC_Select_CH8();
	  		  			 	  HAL_ADC_Start(&hadc1);
	  		  			 	  HAL_ADC_PollForConversion(&hadc1, 1000);
	  		  			 	  Acc1z = HAL_ADC_GetValue(&hadc1);;
	  		  			 	  HAL_ADC_Stop(&hadc1);

	  		  			 	  ADC_Select_CH4();
	  		  			 	  HAL_ADC_Start(&hadc1);
	  		  			 	  HAL_ADC_PollForConversion(&hadc1, 1000);
	  		  			 	  gyro1 = HAL_ADC_GetValue(&hadc1);;
	  		  			 	  HAL_ADC_Stop(&hadc1);

	  		  	//		 	  map_ecg = round((float)ecg/4096.0*180.0);
	  		  	//		 	  map_hasil = (ecg_lpf*150);
	  		  	//		 	  sprintf(ecg_data, "add 1,0,%d",map_ecg);
	  		  	//		 	  sprintf(hasil_data, "add 5,0,%d",map_hasil);
	  		  	//		 	  //map_hasil = round((float)ecg[0]/4096.0*200.0);
	  		  	////		      sprintf(ecg_data, "add 5,0,%d",map hasil);
	  		  	//		 	  HAL_UART_Transmit(&huart1, ecg_data, strlen(ecg_data),10);
	  		  	//		 	  HAL_UART_Transmit(&huart1, Cmd_End, 3, 10);
	  		  	//		 	  HAL_UART_Transmit(&huart1, hasil_data, strlen(hasil_data), 10);
	  		  	//		 	  HAL_UART_Transmit(&huart1, Cmd_End, 3, 10);
	  		  			 	  Kalman();
	  		  			 	  PanTompkins();
	  		  			 	  vel();
	  		  			 	  Fuzzy();
	  		  			 	  time();

	  		  			 	  if(outf>=65.0){
	  		  			 	   	 // HAL_GPIO_WritePin(GPIOB,GPIO_PIN_15,1);
	  		  			 		  tmr=1;
	  		  			 		  fes=1;
	  		  			 		  HAL_UART_Transmit_IT(&huart2, myData, 0);
	  		  			 	  }
	  		  			 	 if(fes==1){
								  HAL_GPIO_WritePin(GPIOB,GPIO_PIN_15,1);
								  on++;
								  off=0;
								  if(on==750){
									fes2=1;
									fes=0;
								  }

							  }
	  		  			 	 if(fes2==1){
	  		  			 		 off++;
	  		  			 		 on=0;
	  		  			 		 HAL_GPIO_WritePin(GPIOB,GPIO_PIN_15,0);
	  		  			 		 if(off==750){
	  		  			 			 fes=1;
	  		  			 			 fes2=0;
	  		  			 		 }
	  		  			 	 }

	  		  			 	  if (tmr==1){
	  		  			 		timerCount++;
	  		  			 	  }
	  		  			 	  if (timerCount==45000){
	  		  			 		fes=0;
	  		  			 		fes2=0;
	  		  			 		HAL_GPIO_WritePin(GPIOB,GPIO_PIN_15,0);
	  		  			     	//HAL_UART_Transmit_IT(&huart2, myData, 1);
	  		  			 	  }


	  		  			 			Acc1xa=((UparmAcclX_LPF+360)*10)/100;
	  		  			 			Acc1xb=((UparmAcclX_LPF+360)*10)-(Acc1xa*100);
	  		  			 			Acc1za=((UparmAcclZ_LPF+360)*10)/100;
	  		  			 			Acc1zb=((UparmAcclZ_LPF+360)*10)-(Acc1za*100);


	  		  			 			gyro1a=((UparmGyroY_LPF+360)*10)/100;
	  		  			 			gyro1b=((UparmGyroY_LPF+360)*10)-(gyro1a*100);

	  		  			 			Uparmac_a=((TiltAc+360)*10)/100;
	  		  			 			Uparmac_b=((TiltAc+360)*10)-(Uparmac_a*100);


	  		  			 			Uparmkal_a=((TiltKal+360)*10)/100;
	  		  			 			Uparmkal_b=((TiltKal+360)*10)-(Uparmkal_a*100);

	  		  			 			gyroUparma=((GyroUparm+6000)*10)/10000;
	  		  			 			gyroUparmb=(((GyroUparm+6000)*10)/100)-(gyroUparma*100);
	  		  			 			gyroUparmc=((GyroUparm+6000)*10)-((gyroUparma*10000)+(gyroUparmb*100));

	  		  			 		    VUparmx = (Acc1x*3.3)/4095;
	  		  			 		    VUparmz = (Acc1z*3.3)/4095;
	  		  			 		   	VgyroUparm = (gyro1*3.3)/4095;


	  		  			 			VUparmx_a = (VUparmx*100)/100;
	  		  			 			VUparmx_b = (VUparmx*100)-(VUparmx_a*100);
	  		  			 			VUparmz_a = (VUparmz*100)/100;
	  		  			 			VUparmz_b = (VUparmz*100)-(VUparmz_a*100);

	  		  			 			VgyroUparm_a = (VgyroUparm*100)/100;
	  		  			 			VgyroUparm_b = (VgyroUparm*100)-(VgyroUparm_a*100);

	  		  			 			Vecg_a = ((Vecg+50)*100)/100;
	  		  			 			Vecg_b = ((Vecg+50)*100)-(Vecg_a*100);


	  		  			 			myData[0]='e';

	  		  			 			myData[1]=UparmAcclX_LPF/100;
	  		  			 			myData[2]=UparmAcclX_LPF-(myData[1]*100);
	  		  			 			myData[3]=UparmAcclZ_LPF/100;
	  		  			 		    myData[4]=UparmAcclZ_LPF-(myData[3]*100);
	  		  			 			myData[5]=UparmGyroY_LPF/100;
	  		  			 			myData[6]=UparmGyroY_LPF-(myData[5]*100);
	  		  			 			myData[7]=ecg/100;
	  		  			 			myData[8]=ecg-(myData[7]*100);
	  		  		//
	  		  			 			myData[9]=Uparmac_a;
	  		  			 			myData[10]=Uparmac_b;
	  		  			 			myData[11]=Uparmkal_a;
	  		  			 		    myData[12]=Uparmkal_b;
	  		  	//		 		    myData[13]=Uparmkal_a;
	  		  	//		 		   	myData[14]=Uparmkal_b;
	  		  			    		myData[13]=(kecepatan+1000)/100;
	  		  			 		   	myData[14]=(kecepatan+1000)-(myData[13]*100);

	  		  			 			myData[15]=ri;

	  		  			 			myData[16]=Vecg_a;
	  		  			 			myData[17]=Vecg_b;

	  		  			 			myData[18]=(hr*100)/100;
	  		  			 			myData[19]=(hr*100)-(myData[18]*100);

	  		  			 			myData[20]=((durasi+20)*100)/100;
	  		  			 			myData[21]=((durasi+20)*100)-(myData[20]*100);

	  		  			 			myData[22]=((outf+200)*10)/100;
	  		  			 			myData[23]=((outf+200)*10)-(myData[22]*100);

//	  		  			 		    myData[24]=((value_rmssd+20)*100)/100;
//	  		  			 			myData[25]=((value_rmssd+20)*100)-(myData[24]*100);



//	  		  			 			myData[20]=((ecg_lpf+100)*10)/100;;
//	  		  			 			myData[21]=((ecg_lpf+100)*10)-(myData[20]*100);
//
//	  		  			 			myData[22]=((ecg_hpf+50)*100)/100;
//	  		  			 		    myData[23]=((ecg_hpf+50)*100)-(myData[22]*100);
//
//	  		  			 		    myData[24]=((deriv+200)*10)/100;
//	  		  			 		    myData[25]=((deriv+200)*10)-(myData[24]*100);
//
//	  		  			 		    myData[26]=(squar+1000)/100;
//	  		  			 		    myData[27]=(squar+1000)-(myData[26]*100);
//
//	  		  			 			myData[28]=((mav+100)*10)/100;
//	  		  			 			myData[29]=((mav+100)*10)-(myData[28]*100);
//
//	  		  			 			myData[30]=((mav1+100)*10)/100;
//	  		  			 			myData[31]=((mav1+100)*10)-(myData[30]*100);
//
//	  		  			 		    myData[32]=((thr+200)*10)/100;
//	  		  			 		    myData[33]=((thr+200)*10)-(myData[32]*100);
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

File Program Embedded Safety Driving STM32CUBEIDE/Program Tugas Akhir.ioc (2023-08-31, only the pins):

Mcu.UserName=STM32F411CEUx
PA1.Signal=ADCx_IN1
PA10.Signal=USART1_RX
PA11.Signal=USB_OTG_FS_DM
PA12.Signal=USB_OTG_FS_DP
PA13.Signal=SYS_JTMS-SWDIO
PA14.Signal=SYS_JTCK-SWCLK
PA15.Signal=USART1_TX
PA2.Signal=USART2_TX
PA3.Signal=USART2_RX
PA4.Signal=ADCx_IN4
PA5.Signal=ADCx_IN5
PA8.Signal=S_TIM1_CH1
PB0.Signal=ADCx_IN8
PB15.Signal=GPIO_Output
PB3.Signal=SPI1_SCK
PB4.Signal=SPI1_MISO
PB5.Signal=SPI1_MOSI
PB7.Signal=S_TIM4_CH2
PC13-ANTI_TAMP.Signal=GPIO_Output

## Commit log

2023-08-31 Interface Safety Driving Delphi7
    [Project1.cfg]
2023-08-31 /Program Embedded Safety Driving STM32CUBEIDE
    [TEST Debug.cfg]
2023-08-31 Eagle PCB Safety Driving Using ECG And Postural
    [FES.brd, FES.sch, Modul1.brd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]

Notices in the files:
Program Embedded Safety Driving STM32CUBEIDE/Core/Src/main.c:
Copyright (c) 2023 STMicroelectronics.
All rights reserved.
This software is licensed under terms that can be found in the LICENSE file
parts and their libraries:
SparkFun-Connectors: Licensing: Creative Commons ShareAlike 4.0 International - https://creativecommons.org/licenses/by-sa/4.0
